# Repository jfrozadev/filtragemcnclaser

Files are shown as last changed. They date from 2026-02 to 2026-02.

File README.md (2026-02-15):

# 📦 CAIXA DE FILTRAGEM 250×250×250mm
## ✅ VERSÃO 13.0 - Cantoneiras M3 + Clips Retenção por Filtro

---

## ⚠️ CORREÇÕES DESTA VERSÃO (CRÍTICAS):

### 🔧 PROBLEMAS ORIGINAIS:
1. Os arquivos originais tinham **dentes e ranhuras nas mesmas posições Y**
2. Os **slots das divisórias** nas laterais foram removidos (trilhos 3D substituem)

### ✅ CORREÇÕES APLICADAS:

**1. Frontal e Traseira - Padrão de dentes INVERTIDO:**
   - Antes: Dentes em Y=25-50, 75-100, 125-150, 175-200, 225-250
   - Agora: Dentes em Y=**0-25**, **50-75**, **100-125**, **150-175**, **200-225**

**2. Sistema de Encaixe Complementar:**
   ```
   LATERAL (ranhuras):    ░░███░░███░░███░░███░░███
   FRONTAL (dentes):      ███░░███░░███░░███░░███░░
   Posição Y:            0  25 50 75 100 ... 225 250
   
   █ = Sólido (25mm)
   ░ = Recuo/Dente (25mm)
   ```

**3. Slots das Divisórias REMOVIDOS:**
   - Divisórias agora deslizam nos trilhos 3D impressos
   - Sem abas nas divisórias, sem slots nas laterais

**4. Lateral Direita ESPELHADA:**
   - Slots espelhados para encaixar corretamente quando montada

**5. Filtro Wega:** 220×160mm (22×16cm) - VERIFICADO ✓

---

## ⚙️ PARÂMETROS DE CORTE

| Parâmetro | Valor |
|---|---|
| **Potência** | S1000 (100%) |
| **Velocidade** | F150 mm/min |
| **Passagens** | 3× |
| **Air Assist** | OBRIGATÓRIO |

---

## 📐 DIMENSÕES DO CUBO 250mm

### Estrutura Principal:
| Peça | Dimensão | Espessura | Qtd |
|---|---|---|-----|
| Laterais (Esq/Dir) | 250×250mm | 3mm | 2 |
| Frontal (entrada) | 244×250mm | 3mm | 1 |
| Traseira (saída) | 244×250mm | 3mm | 1 |
| Tampa | 250×250mm | 3mm | 1 |
| Base | 250×250mm | 3mm | 1 |

### Divisórias (retângulos simples 244×240mm, deslizam nos trilhos):
| Peça | Corpo | Furo do Filtro | Espessura Filtro |
|---|---|---|---|
| Manta G3 | 244×240mm | 200×200mm | **10mm** |
| GM Cabine Bosch | 244×240mm | **212×200mm** (reduzida) | **20mm** |
| Wega Motor | 244×240mm | **223×160mm** | **10mm** |
| **FILTRO HEPA** | 244×240mm | **100×130mm** (reduzida) | borda **2mm** esp. × 5mm larg. |
| Tela Carvão (×2) | 244×240mm | Abertura 200×200mm + 16 furos M3 | — |

### Compartimento de Carvão Ativado:
| Item | Descrição |
|---|---|
| Telas MDF (×2) | 244×240mm com abertura central 200×200mm (11_GAVETA.nc) |
| Caixa MDF (quadro) | 4 bordas ao redor da abertura com encaixe tela (13_CAIXA_CARVAO.nc) |
| Tela alumínio | Mosquiteira fixada com 16 paraf. M3+arruela por tela |
| Posições (slots) | X=190mm (Tela 1) e X=230mm (Tela 2) |
| Espaço interno | 37mm entre telas → ~500g carvão ativado |
| Caixa montada | Quadro 200×200×37mm (4 bordas encaixadas ao redor da abertura) |
| Abas conexão tela | 8 abas (10×3mm) encaixam em 8 slots nas telas, juntando 2 MDF |
| Cantoneiras (3D print) | 16 cantoneiras L-bracket M3 – SNAP_TAMPA.scad |
| Retenção filtro (3D print) | 28 clips paramétricos (8 Manta + 8 GM + 4 Wega + 8 HEPA) – SNAP_TAMPA.scad |

---

## 📁 ARQUIVOS DE CORTE (12 total)

| # | Arquivo | Descrição |
|---|---|---|
| 1 | `01_LATERAL_ESQ.nc` | 250×250mm com ranhuras + furos M3 Ø3.5mm + furos M2 trilhos |
| 2 | `02_LATERAL_DIR.nc` | Idêntica (espelhada) + furos M3 Ø3.5mm + furos M2 trilhos |
| 3 | `03_FRONTAL.nc` | 244×250mm com dentes + furo 70mm + furos M3 Ø3.5mm |
| 4 | `04_TRASEIRA.nc` | 244×250mm com dentes + furo 150mm + furos M3 Ø3.5mm |
| 5 | `05_TAMPA.nc` | 250×250mm + 8 furos M3 Ø3.5mm (cantoneiras) |
| 6 | `06_BASE.nc` | 250×250mm + 8 furos M3 Ø3.5mm + 4 furos pés de borracha |
| 7 | `07_DIVISORIA_MANTA_G3.nc` | 244×240mm + furo 200×200mm + 8 furos M3 Ø3.5mm |
| 8 | `08_DIVISORIA_GM.nc` | 244×240mm + furo **212×200mm** + 8 furos M3 Ø3.5mm |
| 9 | `09_DIVISORIA_WEGA.nc` | 244×240mm + furo **223×160mm** + **4** furos M3 Ø3.5mm |
| 10 | `10_DIVISORIA_HEPA.nc` | 244×240mm + furo **100×130mm** + 8 furos M3 Ø3.5mm |
| 11 | `11_GAVETA.nc` | 2× tela carvão 244×240mm (abertura 200×200, M3 + 8 slots quadro) |
| 12 | `12_FLANGES.nc` | Entrada 70mm + Saída 150mm |
| 13 | `13_CAIXA_CARVAO.nc` | 4× bordas MDF quadro carvão (ao redor abertura, c/ abas tela) |
| 14 | `TRILHO_FILTRO.scad` | Trilhos deslizantes 3D (filtros removíveis, Ender 3) |
| 15 | `TRILHO_PRINT_LAYOUT.scad` | Layout de impressão COMPLETO (10 batches, 200×200mm) |
| 16 | `SNAP_TAMPA.scad` | Cantoneiras M3 + vedação divisória particionada |
| 17 | `FLANGE_150mm.scad` | Flange 150mm (180×180mm base, cabe em 200×200) |
| 18 | `FLANGE_70mm.scad` | Flange 70mm (100×100mm base) |
| 19 | `TRILHO_3D.html` | Visualização 3D interativa dos trilhos |

---

## 🔧 SISTEMA DE ENCAIXE

### Finger Joints (Laterais ↔ Frontal/Traseira):
```
LATERAL (ranhuras):     FRONTAL (dentes):
    ┌───┐                   ├───┤
────┘   └────           ────┤   ├────
 (3mm profundidade)      (3mm salientes)
 
Os DENTES do frontal/traseira entram
nas RANHURAS das laterais!
```

### Divisórias (Deslizam nos Trilhos 3D):
```
LATERAL:               DIVISÓRIA:
   │     │                244×240mm
   │ ███ │ ← trilho 3D    ──────
   │ ││  │                │ MDF │  ← desliza no U
   │ ███ │ ← trilho 3D    ──────
   │     │
   
Trilhos em U fixados com cola CA + Allen M2×5mm
Divisórias deslizam de cima, sem abas/slots
```

### Compartimento Carvão (Quadro ao Redor da Abertura):
```
LATERAL:
   │ ▭ │ X=190mm  (Tela 1)
   │   │  ← quadro carvão (37mm) ao redor da abertura
   │ ▭ │ X=230mm  (Tela 2)
   
VISTA FRONTAL (quadro entre as 2 telas):
   ┌────────────────────────┐
   │  ┌──────────────────┐  │
   │  │  abertura 200×200  │  │ ← borda 22mm da tela
   │  │  (carvão + tela)   │  │
   │  └──────────────────┘  │
   └────────────────────────┘
     ↑ quadro MDF (4 bordas com encaixe tab-slot)

VISTA LATERAL (corte mostrando encaixe):
   Tela2 ═══╤════════╤═══  ← aba atravessa slot
            │ carvão │
            │  37mm  │     ← borda MDF 3mm
            │        │
   Tela1 ═══╧════════╧═══  ← aba atravessa slot

4 bordas MDF formam quadro ao redor da abertura
8 abas (2/borda) atravessam 8 slots nas telas
Encaixes juntam Tela 1 + Quadro + Tela 2
Tela alumínio (mosquiteira) parafusada c/ M3+arruela
16 furos 3.5mm por placa (4 por lado)
Encaixam nos trilhos laterais como as outras divisórias
```

### Trilhos Deslizantes (Filtros Removíveis por Cima):
```
VISTA LATERAL (corte da lateral esquerda):
   TAMPA (remove parafusos M3)
   │                    │
   │  ↑ filtro sobe ↑   │
   │  ┌───────────┐  │
   │╣█╣ divisória  ╣█╣│  ← trilho U impresso 3D
   │╣█╣ MDF 3mm   ╣█╣│    colado na lateral
   │╣█╣           ╣█╣│
   │  └───────────┘  │
   │   └─ trava ─┘   │  ← clipe de retenção (evita cair)
   └──────────────────┘
   BASE

PERFIL DO TRILHO (seção transversal):
   ┌─┐   ┌─┐
   │ │   │ │  ← abas guiam o MDF
   │ ╠═══╣ │  ← canal (esp. filtro + 0.4mm)
   └─┴───┴─┘  ← base (cola no MDF lateral)

2 METADES com junta reta (122mm + 122mm = 244mm):
   Cabe na Ender 3 (200×200mm)
   Fixadas com cola CA + parafuso M2 (sem dovetail)
```

| Filtro | Pos X | Canal | Peças (2×metade A + 2×metade B) |
|---|---|---|---|
| Manta G3 | 50mm | 17mm | 4 |
| GM Cabine | 75mm | 21mm | 4 |
| Wega Motor | 125mm | 46mm | 4 |
| HEPA | 155mm | 26mm | 4 |
| Tela Carvão 1 | 190mm | 3.4mm | 4 |
| Tela Carvão 2 | 230mm | 3.4mm | 4 |
| **TOTAL** | | | **24 + 6 puxadores + 6 travas = 36** |

### 🖨️ LAYOUT IMPRESSÃO 3D (Ender 3 - 200×200mm)

**Todas as peças cabem na mesa de 200×200mm!**

| Batch | Peças | Qtd | Tempo | Tamanho |
|---|---|-----|---|---|
| 1 | Trilhos Tela Carvão (3.4mm) | 8 | ~50min | 80×122mm ✓ |
| 2 | Trilhos Manta G3 (17mm) | 4 | ~1h | 88×122mm ✓ |
| 3 | Trilhos GM Cabine (21mm) | 4 | ~1h20 | 109×122mm ✓ |
| 4 | Trilhos HEPA (26mm) | 4 | ~1h30 | 129×122mm ✓ |
| 5A | Trilhos Wega A (46mm) | 2 | ~1h | 103×122mm ✓ |
| 5B | Trilhos Wega B (46mm) | 2 | ~1h | 103×122mm ✓ |
| 6 | Puxadores + Travas | 12 | ~45min | 200×33mm ✓ |
| 7 | Cantoneiras + Retenção | 44 | ~5h30 | 184×135mm ✓ |
| 8 | Vedação Divisória (8 seg) | 8 | ~1h30 | 130×65mm ✓ |
| 9 | Flange 150mm | 1 | ~3h | 180×180mm ✓ |
| 10 | Flange 70mm | 1 | ~1h30 | 100×100mm ✓ |
| **TOTAL** | | **62** | **~15h30** | |

**Arquivo:** `TRILHO_PRINT_LAYOUT.scad` — abrir no OpenSCAD, descomentar batch desejado, F6+F7 para exportar STL.

### Sistema de Fixação:
```
CANTONEIRAS M3 (fechar caixa - tampa + base):
  16 cantoneiras L-bracket impressas em PLA/PETG
  Flange horiz: 20×15×3mm | Flange vert: 20×18×3mm
  Furos M3 Ø3.5mm nos 6 painéis (tampa, base, 4 paredes)
  Fixação: 32× M3×8mm + 32× porca M3 (2 por cantoneira)
  Posições laterais: X=100mm X=173mm, a Y=10mm (base) e Y=240mm (topo)
  Posições frontal/traseira: X=82mm X=162mm, a Y=10mm e Y=240mm
  Abertura fácil: desapertar 16 parafusos pela tampa → tampa sai
  Vedação: compressão MDF-cantoneira + fita vedação opcional

RETENÇÃO FILTRO (fixar filtro na divisória - parafuso M3):
  28 clips retenção impressos em PLA/PETG
  8 Manta G3 + 8 GM Cabine + 4 Wega + 8 HEPA
  Base: 20×15×3mm | Braço: 20×2×12mm | Aba: 20×10×2mm
  8 furos M3 Ø3.5mm por divisória ao redor da abertura do filtro:
    Manta G3: (12,80)(12,160)(232,80)(232,160)(88,10)(156,10)(88,230)(156,230)
    GM Cabine: (5,80)(5,160)(239,80)(239,160)(82,7)(162,7)(82,232)(162,232)
    Wega: (6,80)(6,160)(238,80)(238,160)(82,19)(162,19)(82,221)(162,221)
    HEPA: (57,90)(57,150)(187,90)(187,150)(102,40)(142,40)(102,200)(142,200)
  Fixação: parafuso M3×10mm + porca M3

TOTAL: 44 peças (16 cantoneiras + 28 clips retenção filtro)

Vedação divisória (opcional):
  8 segmentos com encaixes dovetail (~122mm cada)
  Particionada para caber na mesa 200×200mm
```

---

## 🛠️ ORDEM DE MONTAGEM

1. **Base** → Colocar na mesa
2. **Lateral Esquerda** → Cole sobre a borda da base
3. **Lateral Direita** → Paralela, a 244mm de distância
4. **Frontal** → Dentes nos slots das laterais
5. **Traseira** → Igual ao frontal
6. **Trilhos 3D** → Fixar nas laterais com cola CA + parafuso Allen M2×5mm (furos Ø2.5mm pré-cortados, 12/lateral)
7. **Divisórias filtro** → Deslizar de cima pelos trilhos + fixar cada filtro com 8 clips retenção (M3×10mm) ao redor da abertura
8. **Telas carvão (×2)** → Deslizar nos trilhos X=190 e X=230
9. **Caixa carvão** → Encaixar 4 tiras + preencher com carvão
10. **Tampa** → Posicionar no topo, fixar com 16 cantoneiras + 32 parafusos M3×8mm

---

## 🎯 VERIFICAÇÃO 3D

Abra `MONTAGEM_3D.html` no navegador para:
- Ver a montagem passo a passo (12 passos)
- Verificar encaixes visuais, incluindo trilhos
- Rotacionar e dar zoom no modelo

Abra `TRILHO_3D.html` para:
- Ver trilhos deslizantes em detalhe
- Animar deslizamento dos filtros
- Ver encaixe dovetail das 2 metades

| Divisória | Posição X | Espessura | Espaço até próximo | Função |
|---|---|---|---|---|
| *(plenum entrada)* | *3mm* | — | *47mm→G3* | *Expansão do ar (47mm)* |
| Manta G3 | **50mm** | 10mm | 22mm→GM | Pré-filtro (partículas grandes) |
| GM Cabine Bosch | **75mm** | 20mm | 47mm→Wega | Filtro cabine (partículas médias) |
| Wega Motor | **125mm** | 45mm | 27mm→HEPA | Filtro motor (partículas finas) |
| **FILTRO HEPA** | **155mm** | 25mm | 32mm→Tela 1 | **Filtro HEPA** |
| Tela Carvão 1 | **190mm** | 3mm (MDF) | 37mm→Tela 2 | Retém carvão (lado interno) |
| Tela Carvão 2 | **230mm** | 3mm (MDF) | 17mm→Traseira | Retém carvão (lado traseira) |

---

## 📋 MATERIAIS

- MDF 3mm: ~15 chapas 300×300mm
- Manta G3 (pré-filtro) 10mm - fixada com 8 clips 3D (CLIP_MANTA_G3.scad)
- Filtro GM Cabine Bosch 20mm
- Filtro Wega Motor 45mm
- **Filtro HEPA** (110×140×25mm)
- Carvão ativado ~500g (granulado)
- Tela alumínio mosquiteira (2× para telas carvão)
- 32× Parafuso M3 + arruela (16 por tela)
- Cola PVA + Silicone
- 16× Cantoneiras L-bracket impressas em PLA/PETG (SNAP_TAMPA.scad)
- 32× Parafuso M3×8mm + 32× porca M3 (fixação cantoneiras tampa/base)
- 28× Clips retenção filtro impressos em PLA/PETG (SNAP_TAMPA.scad)
- 28× Parafuso M3×10mm + 28× porca M3 (fixação clips retenção nas divisórias)
- 24× Trilhos deslizantes impressos em PLA/PETG (TRILHO_FILTRO.scad)
- 6× Puxadores + 6× Travas impressos (TRILHO_FILTRO.scad)
- 8× Vedação divisória (opcional) impressos (SNAP_TAMPA.scad)
- 2× Flanges impressos (FLANGE_150mm.scad + FLANGE_70mm.scad)
- 24× Parafuso Allen M2×5mm (fixação trilhos, 12 por lateral — rosca no PLA, sem porca)
- Filamento PLA/PETG ~150g

---

**Versão:** 13.0 — Cantoneiras M3 (tampa/base) + clips retenção filtro (divisórias)  
**Data:** Fevereiro 2026

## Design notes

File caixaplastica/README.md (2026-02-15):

# 📦 CAIXA PLÁSTICA FILTRAGEM
## Caixa Organizadora Ordene 30L (307×425×305mm)
### MDF 300×300×3mm INTEIRO — só corte da abertura + furos M3

---

## 💡 CONCEITO

Caixa plástica comercial como estrutura. **MDF 300×300mm usado inteiro** (sem cortar o contorno externo).
O MDF encaixa justo na largura interna da caixa (~301mm). Guias 3D no fundo (50mm de altura) + **barras anti-tombo** no aro superior mantêm cada divisória firme.

```
┌─────────── CAIXA PLÁSTICA ───────────┐
│  ══ BARRA ANTI-TOMBO (aro) ══════    │ ← segura topo do MDF
│  MDF 300mm ← encaixa justo (301mm) → │
│  ┌───────────────────────────────┐    │
│  │        ┌──────────┐          │    │
│  │        │ ABERTURA │  ← laser │    │
│  │        │ FILTRO   │          │    │
│  │        └──────────┘          │    │
│  │     (furos M3 ao redor)      │    │
│  └───────────────────────────────┘    │
│  ──█──────────────────────────█──    │ ← guias piso 50mm
└───────────────────────────────────────┘
```

### Sustentação do MDF:
- ✅ **Embaixo**: Guias piso U (50mm alt.) — coladas no fundo
- ✅ **Em cima**: Barras anti-tombo — apoiam no aro da caixa
- ✅ **Laterais**: Paredes da caixa (301mm vs 300mm MDF)
- ✅ **3 eixos de contenção** → MDF não tomba!

### Vantagens:
- ✅ **Zero corte externo** — só abertura + furos
- ✅ Caixa pronta, vedada, com tampa
- ✅ MDF 300×300 direto da loja (sem desperdiço)
- ✅ Guias piso coladas + barras topo — **MDF não tomba!**
- ✅ Divisórias removíveis (levanta e sai)
- ✅ Menos tempo de laser (só aberturas)

---

## 📐 DIMENSÕES

### Caixa Plástica (Ordene Radical Color 30L):
| Parâmetro | Valor |
|---|---|
| **Modelo** | Caixa Organizadora Plástico Transparente 30L |
| **Código** | 87164742 (Leroy Merlin) |
| **EAN** | 7898335072150 |
| **Externo** | 307 × 425 × 305 mm (L × P × A) |
| **Interno (est.)** | ~301 × 419 × 297 mm |
| **Parede** | ~3mm PP |

> ⚠️ **MEÇA SUA CAIXA!** Ajuste os parâmetros no OpenSCAD se necessário.

### MDF:
| Parâmetro | Valor |
|---|---|
| **Chapa** | 300 × 300 × 3 mm (padrão, sem cortar) |
| **Encaixe** | 300mm no vão de 301mm (0.5mm folga/lado) |
| **Altura** | 300mm (sobra ~3mm acima do interno — ok com tampa) |

### Guia de Posição PISO (3D print):
| Parâmetro | Valor |
|---|---|
| **Tipo** | Canal U colado no fundo |
| **Canal** | 3.4mm (MDF 3 + folga 0.4) |
| **Paredes** | 1.5mm cada |
| **Base** | 6.4mm × 2mm |
| **Altura guia** | **50mm** (anti-tombo) |
| **Comprimento** | 80mm |
| **Fixação** | Super Bonder gel |
| **Qtd** | 12 (6 posições × 2 lados) |

### Barra Anti-Tombo (3D print):
| Parâmetro | Valor |
|---|---|
| **Tipo** | Barra com rasgos — apoiada no aro da caixa |
| **Largura** | 15mm (assenta no aro) |
| **Altura** | 20mm |
| **Rasgo** | 3.4mm × 14mm prof. (MDF entra por baixo) |
| **Seção 1** | 135mm — G3 + GM + Wega (3 rasgos) |
| **Seção 2** | 125mm — HEPA + C1 + C2 (3 rasgos) |
| **Fixação** | Apoio por gravidade (não precisa cola) |
| **Qtd** | 4 (2 seções × 2 lados) |

---

## 🎯 LAYOUT DOS FILTROS

```
ENTRADA Ø70mm                                    SAÍDA Ø150mm
    │                                                 │
    ▼                                                 ▼
┌───┬───┬────┬─────┬──────┬────┬───┬───┬───┬────┬────┐
│   │G3 │    │ GM  │      │WEGA│   │HPA│   │ C1 │ C2 │
│50 │   │ 95 │     │ 165  │    │245│   │310│    │350 │
└───┴───┴────┴─────┴──────┴────┴───┴───┴───┴────┴────┘
0mm              profundidade (425mm ext)            419mm
```

| # | Divisória | Pos Y | Abertura | Esp. Filtro | Furos M3 |
|---|---|---|---|---|---|
| 1 | Manta G3 | 50mm | 200×200mm | 10mm | 8 |
| 2 | GM Cabine | 95mm | 212×200mm | 20mm | 8 |
| 3 | Wega Motor | 165mm | 223×160mm | 45mm | 4 |
| 4 | HEPA | 245mm | 100×130mm | 25mm | 8 |
| 5 | Tela Carvão 1 | 310mm | 200×200mm | 3mm (MDF) | 16 |
| 6 | Tela Carvão 2 | 350mm | 200×200mm | 3mm (MDF) | 16 |

### Espaçamentos:
| Trecho | mm | Função |
|---|----|---|
| Parede → G3 | 50 | Plenum entrada |
| G3 → GM | 35 | Expansão |
| GM → Wega | 50 | Expansão |
| Wega → HEPA | 35 | Expansão |
| HEPA → Tela 1 | 40 | Expansão |
| Tela 1 → Tela 2 | 37 | Carvão ativado (~700g) |
| Tela 2 → Parede | 66 | Plenum saída |

---

## ⚙️ CORTE CNC LASER

| Parâmetro | Valor |
|---|---|
| **CNC** | Two Trees TTS-10 |
| **Material** | MDF 3mm |
| **Potência** | S900 |
| **Velocidade** | F200 mm/min |
| **Passagens** | 4× |
| **Air Assist** | OBRIGATÓRIO |

**Importante:** Os NC files cortam APENAS a abertura e os furos M3. O contorno externo 300×300mm **NÃO é cortado**.

---

## 📁 ARQUIVOS

### Corte CNC (5 divisórias):
| # | Arquivo | Abertura | Furos M3 |
|---|---|---|---|
| 1 | `01_DIVISORIA_MANTA_G3.nc` | 200×200mm em (50,50) | 8 |
| 2 | `02_DIVISORIA_GM.nc` | 212×200mm em (44,50) | 8 |
| 3 | `03_DIVISORIA_WEGA.nc` | 223×160mm em (38.5,70) | 4 |
| 4 | `04_DIVISORIA_HEPA.nc` | 100×130mm em (100,85) | 8 |
| 5 | `05_TELA_CARVAO.nc` | 200×200mm em (50,50) | 16 (×2 chapas) |

### Impressão 3D:
| # | Arquivo | Descrição |
|---|---|---|
| 6 | `GUIA_POSICAO.scad` | Guia U parametrizável (OpenSCAD) |

### Visualização:
| # | Arquivo | Descrição |
|---|---|---|
| 7 | `MONTAGEM_3D.html` | Montagem 3D interativa (12 passos) |

### Reutilizados (pasta pai):
| Arquivo | Descrição |
|---|---|
| `../FLANGE_70mm.scad` | Flange entrada Ø70mm |
| `../FLANGE_150mm.scad` | Flange saída Ø150mm |
| `../SNAP_TAMPA.scad` | Clips retenção filtro (M3) |

---

## 🔧 FUROS NA CAIXA (Furadeira)

### Apenas flanges! (serra-copo)
```
FRONTAL:                      TRASEIRA:
┌──────────────────┐          ┌──────────────────┐
│    ┌────────┐    │          │  ┌────────────┐  │
│    │ Ø70mm  │    │          │  │  Ø150mm    │  │
│    │ENTRADA │    │          │  │  SAÍDA     │  │
│    └────────┘    │          │  └────────────┘  │
│ centro: ~153×152 │          │ centro: ~153×152 │
└──────────────────┘          └──────────────────┘
```

**Laterais: SEM FUROS** — guias são coladas com Super Bonder gel.

---

## 🛠️ ORDEM DE MONTAGEM

1. **Caixa plástica** → Limpar e marcar posições internas
2. **Furar flanges** → Serra-copo Ø70mm (frente) e Ø150mm (atrás)
3. **Instalar flanges 3D** → Parafusar nas faces da caixa
4. **Marcar posições no fundo** → Régua: Y=50, 95, 165, 245, 310, 350mm
5. **Colar guias piso** → Super Bonder gel, 12 guias (50mm alt.) — 2 por posição
6. **Encaixar barras anti-tombo** → 4 barras no aro da caixa (2 seções × 2 lados)
7. **Cortar divisórias** → CNC laser: 7 chapas MDF 300×300mm (só abertura + furos)
8. **Manta G3** → Encaixar MDF na guia Y=50, fixar filtro com 8 clips M3
9. **GM Cabine** → Guia Y=95, filtro 20mm + 8 clips
10. **Wega Motor** → Guia Y=165, filtro 45mm + 4 clips
11. **HEPA** → Guia Y=245, filtro HEPA 25mm + 8 clips
12. **Tela Carvão 1** → Guia Y=310, tela alumínio (16 M3+arruela)
13. **Carvão** → ~700g carvão ativado granulado
14. **Tela Carvão 2** → Guia Y=350, tela alumínio
15. **Tampa** → Fechar com trava original da caixa

---

## 🖨️ IMPRESSÃO 3D

### Guias piso (1 batch):
| Peças | Tamanho cada | Tempo | Filamento |
|---|---|---|---|
| 12 guias (6 pos × 2) | 6.4×80×52mm | ~1h | ~25g |

### Barras anti-tombo (1 batch):
| Peças | Tamanho | Tempo | Filamento |
|---|---|---|---|
| 2× Seção 1 | 135×15×20mm | ~30min | ~8g |
| 2× Seção 2 | 125×15×20mm | ~25min | ~7g |

### Acessórios (pasta pai):
| Item | Qtd | Tempo |
|---|-----|---|
| Flange 70mm | 1 | ~1h30 |
| Flange 150mm | 1 | ~3h |
| Clips retenção | 28 | ~4h |

**Total: ~10h de impressão | ~140g PLA/PETG**

---

## 📋 LISTA DE MATERIAIS

| Item | Qtd | Observação |
|---|-----|---|
| Caixa Ordene 30L | 1 | 307×425×305mm (Leroy Merlin) |
| **MDF 300×300×3mm** | **7** | **Usadas inteiras — sem corte externo** |
| Manta G3 (pré-filtro) | 1 | 200×200×10mm |
| Filtro GM Cabine Bosch | 1 | 212×200×20mm |
| Filtro Wega Motor | 1 | 223×160×45mm |
| Filtro HEPA | 1 | 110×140×25mm |
| Carvão ativado | ~700g | Granulado |
| Tela alumínio mosquiteira | 2× | 250×250mm recortada |
| Parafuso M3×10mm + porca | ~80× | Clips + tela alumínio |
| Arruela M3 | 64× | 32 por tela carvão |
| Super Bonder gel | 1 | Fixar guias no fundo |
| Filamento PLA/PETG | ~100g | Guias + flanges + clips |
| Serra-copo Ø70 + Ø150mm | 1+1 | Para furar flanges |

---

## 🎯 VERIFICAÇÃO 3D

Abra `MONTAGEM_3D.html` no navegador:
- **12 passos interativos** (incluindo barras anti-tombo no passo 6)
- Setas ←→, barra de espaço, Home/End para navegar
- Botão "Mostrar Tudo" para ver montagem completa
- Rotacionar e zoom com mouse

---

**Versão:** 3.0 — Guias 50mm + Barras anti-tombo  
**Data:** Fevereiro 2026

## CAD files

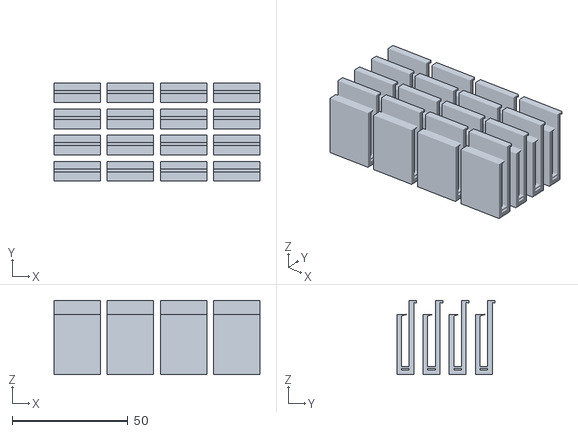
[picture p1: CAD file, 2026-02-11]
PRINT_SNAP_CLIPS.stl
89.0 x 42.4 x 32.0

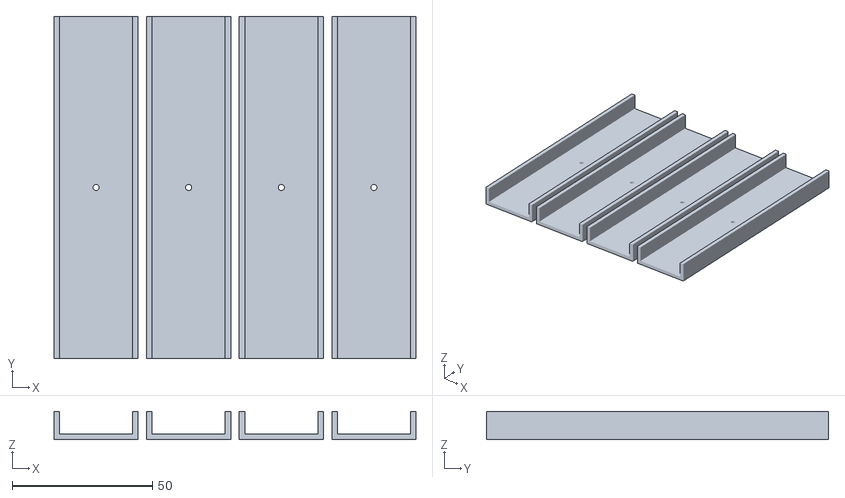
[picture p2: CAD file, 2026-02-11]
PRINT_HEPA.stl
129.0 x 122.0 x 10.0

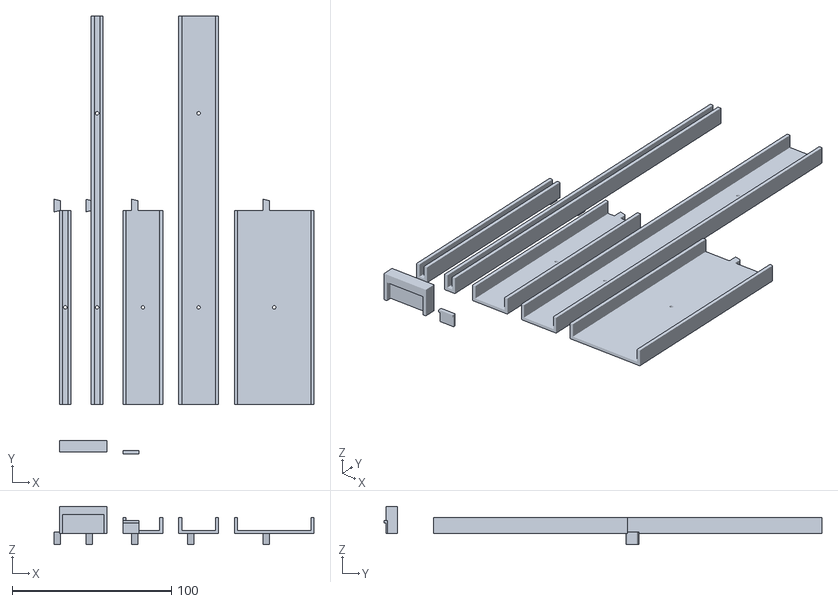
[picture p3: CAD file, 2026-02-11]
TRILHO_FILTRO.stl
163.4 x 275.0 x 24.0

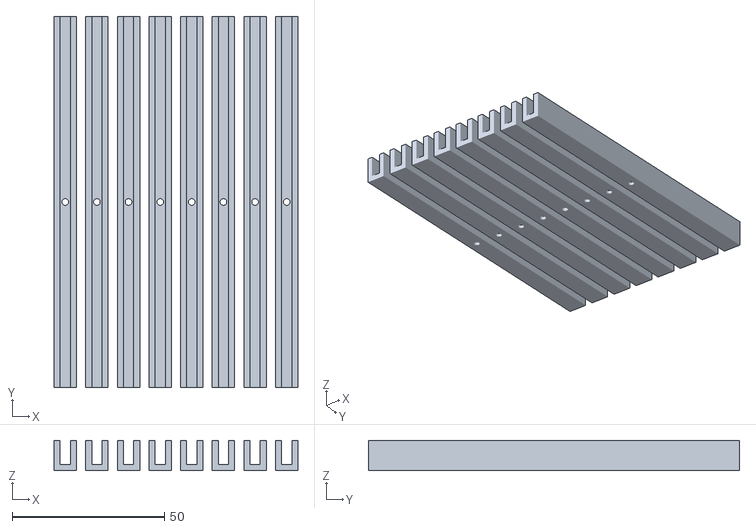
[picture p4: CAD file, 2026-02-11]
TRILHO_PRINT_LAYOUT.stl
80.2 x 122.0 x 10.0

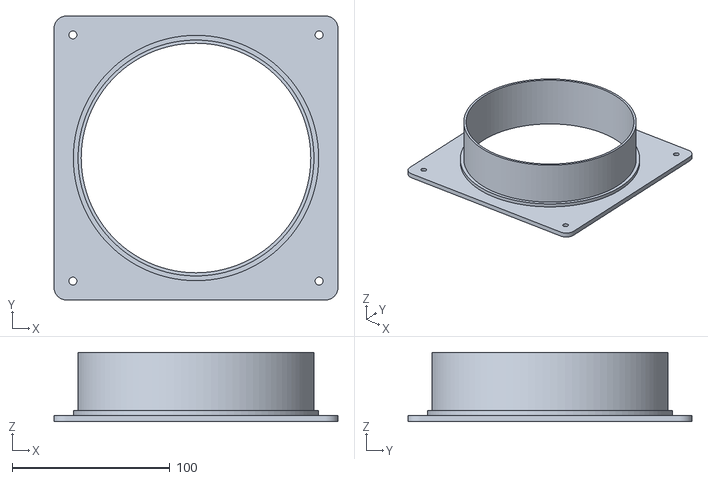
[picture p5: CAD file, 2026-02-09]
FLANGE_150mm.stl
180.0 x 180.0 x 44.0

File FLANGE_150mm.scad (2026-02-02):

// =====================================================
// FLANGE CONECTOR PARA TUBO DE 150mm
// Caixa de Filtragem - Exaustão
// =====================================================
// Para imprimir: Exportar como STL (F6 depois F7)
// Material sugerido: PETG ou ABS
// Preenchimento: 20-30%
// Paredes: 3-4 perímetros
// =====================================================

// PARÂMETROS AJUSTÁVEIS
tubo_diametro = 150;        // Diâmetro interno do tubo (mm)
tubo_espessura = 2;         // Espessura da parede do conector (mm)
tubo_altura = 40;           // Altura do tubo/bocal (mm)
tubo_folga = 0.5;           // Folga para encaixe (mm)

flange_tamanho = 180;       // Tamanho da base quadrada (mm)
flange_espessura = 4;       // Espessura da base (mm)
flange_raio_canto = 8;      // Raio dos cantos arredondados (mm)

furo_diametro = 5;          // Diâmetro dos furos de fixação (mm)
furo_margem = 12;           // Distância do furo até a borda (mm)

// Opção: tubo interno ou externo
// true = tubo encaixa POR DENTRO do duto (mais comum)
// false = tubo encaixa POR FORA do duto
encaixe_interno = true;

// =====================================================
// CÓDIGO - NÃO MODIFICAR ABAIXO
// =====================================================

$fn = 100; // Resolução dos círculos

// Cálculo do diâmetro do bocal
diametro_bocal = encaixe_interno ? 
    tubo_diametro - tubo_folga : 
    tubo_diametro + tubo_espessura*2 + tubo_folga;

module flange_base() {
    // Base quadrada com cantos arredondados
    difference() {
        // Placa base
        hull() {
            for (x = [flange_raio_canto, flange_tamanho - flange_raio_canto])
                for (y = [flange_raio_canto, flange_tamanho - flange_raio_canto])
                    translate([x, y, 0])
                        cylinder(h = flange_espessura, r = flange_raio_canto);
        }
        
        // Furo central para passagem de ar
        translate([flange_tamanho/2, flange_tamanho/2, -1])
            cylinder(h = flange_espessura + 2, d = tubo_diametro - tubo_espessura*2);
        
        // Furos de fixação nos 4 cantos
        for (x = [furo_margem, flange_tamanho - furo_margem])
            for (y = [furo_margem, flange_tamanho - furo_margem])
                translate([x, y, -1])
                    cylinder(h = flange_espessura + 2, d = furo_diametro);
    }
}

module tubo_bocal() {
    translate([flange_tamanho/2, flange_tamanho/2, flange_espessura]) {
        difference() {
            // Tubo externo
            cylinder(h = tubo_altura, d = diametro_bocal);
            
            // Furo interno
            translate([0, 0, -1])
                cylinder(h = tubo_altura + 2, d = diametro_bocal - tubo_espessura*2);
        }
        
        // Anel de reforço na base
        difference() {
            cylinder(h = 3, d = diametro_bocal + 6);
            translate([0, 0, -1])
                cylinder(h = 5, d = diametro_bocal - tubo_espessura*2);
        }
    }
}

module flange_completa() {
    color("white") {
        flange_base();
        tubo_bocal();
    }
}

// Renderizar
flange_completa();

// Info
echo("=== FLANGE 150mm ===");
echo("Diâmetro do tubo:", tubo_diametro, "mm");
echo("Diâmetro do bocal:", diametro_bocal, "mm");
echo("Base:", flange_tamanho, "x", flange_tamanho, "mm");
echo("Altura total:", flange_espessura + tubo_altura, "mm");

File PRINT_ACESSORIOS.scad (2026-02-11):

// ============================================================
// PRINT: ACESSÓRIOS — Puxadores + Travas
// 6× puxadores (30×7.4×17mm) + 6× travas (10×2.2×8mm)
// Mesa: ~200mm × 33mm — cabe na Ender 3 (200×200mm) ✓
// Tempo estimado: ~45min
// ============================================================

use <TRILHO_FILTRO.scad>

gap = 3;

// 6 puxadores em 2 fileiras de 3
for (i = [0:2]) {
    translate([i * 35, 0, 0])
        puxador();
}
for (i = [0:2]) {
    translate([i * 35, 25, 0])
        puxador();
}

// 6 travas ao lado dos puxadores
for (i = [0:5]) {
    translate([110 + i * 15, 0, 0])
        trava();
}

// Guia visual da mesa (não imprime)
%translate([0, 0, -0.5])
    cube([200, 200, 0.1]);

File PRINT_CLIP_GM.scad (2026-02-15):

// ============================================================
// PRINT: CLIPS RETENÇÃO — GM CABINE
// 8 unidades — braço 23mm (espessura filtro 20mm + MDF 3mm)
// Mesa: ~89mm × 56mm — cabe na Ender 3 (200×200mm) ✓
// Divisória: 08_DIVISORIA_GM — Abertura 212×200mm
// ============================================================
// Design estilo clip HVAC (perfil Z com aba sobre o filtro)
// Orientação: base na mesa (Z=0), braço+aba para cima
// Infill recomendado: 80-100%
// Material: PETG (melhor) ou PLA
// Parafusos: 8× M3×16mm + 8× porca M3
// ============================================================
// Posições M3 na divisória (coordenadas NC):
//   (8,80)(8,160)(236,80)(236,160)
//   (82,10)(162,10)(82,230)(162,230)
// ============================================================

use <SNAP_TAMPA.scad>

gap = 3;
ret_w = 20;
aba_y = 8;            // offset Y para aba que estende em -Y
row_h = 15 + aba_y;   // altura total Y por clip = base + aba

// 4 colunas × 2 fileiras = 8 clips GM Cabine (braço 23mm)
for (row = [0:1]) {
    for (col = [0:3]) {
        translate([col * (ret_w + gap), row * (row_h + gap) + aba_y, 0])
            clip_gm();
    }
}

// Guia visual da mesa (não imprime)
%translate([0, 0, -0.5])
    cube([200, 200, 0.1]);

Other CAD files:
FLANGE_70mm.3mf
FLANGE_70mm.scad
FLANGE_70mm.stl
PRINT_CLIP_HEPA.scad
PRINT_CLIP_MANTA.scad
PRINT_CLIP_WEGA.scad
PRINT_GM_CABINE.scad
PRINT_HEPA.scad
PRINT_MANTA_G3.scad
PRINT_SNAP_CLIPS.scad
PRINT_TELA_CARVAO.scad
PRINT_VEDACAO.scad
PRINT_WEGA.scad
SNAP_TAMPA.scad
TRILHO_FILTRO.scad
TRILHO_PRINT_LAYOUT.scad
caixaplastica/GUIA_POSICAO.scad

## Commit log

2026-02-02 Commit inicial - Projeto de Exaustao para CNC Router
    [FLANGE_150mm.scad, FLANGE_70mm.scad]
2026-02-02 Atualizar espessuras corretas dos filtros e etapas individuais na animacao 3D - Wega 50mm, GM Bosch 20mm, HEPA 45mm - Gravacao FILTRO HEPA no arquivo NC
2026-02-02 Redistribuir posicoes dos filtros para espacamento uniforme de 15mm
2026-02-02 Corrigir arquivos de corte das laterais - 4 slots nas novas posicoes (15, 45, 80, 145mm)
2026-02-09 feat: update filter dimensions and simplify G3 divider
    - HEPA filter: 130x250x45mm -> 110x140x25mm (hole 110x140mm centered)
    - Wega filter: 220x160x50mm -> 220x160x45mm (hole 220x160mm corrected)
    - GM cabin filter: 205x220x20mm -> 223x210x20mm (hole 223x210mm centered)
    - Manta G3: simplified from 2-plate sandwich to single plate with glued mesh + clamps (10mm thickness)
    - Updated all NC files with recalculated coordinates (3 passes each)
    - Updated MONTAGEM_3D.html and MODELO_3D.html with correct 3D geometry
    - Updated README.md with new dimensions, spacings and materials
    [FLANGE_150mm.stl, FLANGE_70mm.3mf, FLANGE_70mm.stl]
2026-02-09 feat: compartimento carvao vertical c/ telas MDF + mosquiteira M3
    - 11_GAVETA.nc: 2x placa 244x244mm abertura 200x200mm + 16 furos 3.5mm M3+arruela
    - 01/02 LATERAL: +2 slots carvao (X=180, X=215) espelhados
    - MONTAGEM_3D: createCarbonCompartment() c/ telas verticais, parafusos, mosquiteira
    - SNAP_TAMPA.scad: clips snap-fit tampa + vedacao divisorias (OpenSCAD)
    - README: atualizado materiais, montagem, compartimento carvao
    - Tampa: snap-fit sem parafusos (descricao atualizada)
    [SNAP_TAMPA.scad]
2026-02-09 feat(carvao): redesenhar quadro carvao com bordas ao redor da abertura e encaixes tela
    - Reescrever 13_CAIXA_CARVAO.nc: quadro 200x200x42mm ao redor da abertura
    - 4 bordas MDF com juntas tab-slot nos cantos (8 encaixes)
    - 16 abas (10x3mm) que atravessam slots nas telas, juntando 2 MDF
    - Adicionar 8 slots retangulares (10x3mm) em 11_GAVETA.nc
    - 2 por borda (esq/dir/inf/sup) na borda da abertura 200x200
    - 3 passagens de corte para cada slot
    - Atualizar MONTAGEM_3D.html: posicoes divisorias corrigidas,
    snap-fit clips substituem parafusos, caixa carvao 3D
    - Atualizar SNAP_TAMPA.scad: 16 clips (8+8), pernas 30/24mm,
    slots 22x2mm, instrucoes impressao
    - Adicionar SNAP_FIT_3D.html: visu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
    [SNAP_TAMPA.scad]
2026-02-09 feat(trilhos): adicionar trilhos deslizantes 3D para filtros removiveis
    - TRILHO_FILTRO.scad: design parametrico OpenSCAD
    - perfil U com canal ajustavel por filtro
    - 2 metades com dovetail (122mm+122mm) cabe na Ender 3
    - 6 pares de trilhos (Manta G3, GM, Wega, HEPA, 2x Tela)
    - puxador e trava de retencao inclusos
    - total: 24 trilhos + 6 puxadores + 6 travas = 36 pecas
    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
    [TRILHO_FILTRO.scad]
2026-02-09 feat(trilhos): criar arquivos completos trilhos e atualizar modelos 3D
    Novos arquivos:
    - TRILHO_3D.html: visualizacao 3D interativa dos trilhos
    - animacao deslizar filtros, encaixe dovetail, explodir
    - toggle individual por filtro (G3/GM/Wega/HEPA/Telas)
    - tabela dimensoes e legenda completa
    - TRILHO_PRINT_LAYOUT.scad: layout impressao Ender 3
    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
    [TRILHO_PRINT_LAYOUT.scad]
2026-02-09 fix: corrigir posicoes filtros 3D e layout impressao
    MODELO_3D.html:
    - Corrigir posicoes divisorias (mantag3=0.15, gm=0.40, wega=0.90)
    - Adicionar HEPA (x=1.20), Tela1 (x=1.65), Tela2 (x=2.10)
    - Filtros posicionados upstream (entre divisoria anterior e atual)
    - Adicionar filtro HEPA na visualizacao
    - Corrigir posicao carvao ativado (entre telas, x=1.875)
    - Corrigir animacoes para 6 divisorias
    - Corrigir funcao explodir para todas divisorias
    MONTAGEM_3D.html:
    - Filtros posicionados upstream (posX - fDepth/2)
    - Resolve sobreposicao Wega/HEPA
    TRILHO_3D.html:
    - Filtros posicionados upstream (f.x - espScale/2)
    - homeX em userData para reset correto
    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
    [TRILHO_PRINT_LAYOUT.scad]
2026-02-09 fix: caixa carvao 3D fiel ao NC (200x200x42mm)
    MONTAGEM_3D.html createCarbonCompartment():
    - stripDepth corrigido: carbonDepth-T = 0.42 (42mm corpo quadro)
    - Tiras verticais: 200mm altura (era 244mm)
    - Tiras horizontais: 194mm largura (era 238mm)
    - Posicoes: ao redor da abertura 200x200mm das telas
    (antes estava contra as paredes laterais da caixa)
    - carbonEdges wireframe: 200x200x42mm (era 244x244x45mm)
    - Carvao volume proporcional ao quadro interno
    - Comentarios corrigidos (frameSize=200mm, stripDepth=42mm)
2026-02-09 refactor: reposicionar filtros - 35mm plenum entrada, corpo carvao 37mm
    Problema: filtro Manta G3 a apenas 2mm da face interna frontal.
    Jato do exaustor (70mm) atingia diretamente o centro do filtro
    sem expansao, causando filtragem desigual e entupimento precoce.
    Novas posicoes (centro do slot, mm desde frontal):
    Manta G3: 15 -> 50 (47mm plenum para expansao do ar)
    GM Cabine: 40 -> 75 (22mm gap apos G3)
    Wega: 90 -> 125 (47mm gap apos GM)
    HEPA: 120 -> 155 (27mm gap apos Wega)
    Tela 1: 165 -> 190 (32mm gap apos HEPA)
    Tela 2: 210 -> 230 (37mm corpo carvao)
    Snap-fit reposicionados: X=105/145 -> X=100/173
    Caixa carvao: corpo 42->37mm, tira 48->43mm
    Arquivos alt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
    [TRILHO_FILTRO.scad]
2026-02-09 fix: snap-fit clips 3D geometry (U-bracket conforme SNAP_TAMPA.scad)
    Tampa: clip antigo era L simples (1 perna + gancho).
    Agora mostra bracket em U correto: ponte + perna externa
    30mm + perna interna 24mm + 2 ganchos (conforme SCAD).
    Base: antes mostrava slots escuros dentro do MDF.
    Agora mostra 8 clips invertidos (pernas para cima)
    identicos aos da tampa, espelhados verticalmente.
2026-02-09 simplify: remover furos parafuso da tampa e base (snap-fit nao precisa)
    Tampa: era 287 linhas com 10 furos de parafuso (3 passes cada).
    Agora 112 linhas: so perimetro 250x250mm + gravacao TAMPA.
    Fixacao 100% por clips snap-fit U-bracket.
    Base: removidos 10 furos de parafuso. Mantidos 4 furos
    para pes de borracha (10mm). 339 -> 174 linhas.
    README atualizado com novas descricoes.
2026-02-09 feat: furos M2 fixação trilhos nas laterais + 3D atualizado
    - 01_LATERAL_ESQ.nc: +36 furos Ø2.5mm (M2) para fixação dos trilhos (3 passes)
    - 02_LATERAL_DIR.nc: +36 furos espelhados Ø2.5mm (M2) (3 passes)
    - TRILHO_FILTRO.scad: corrigido array canais (posições atualizadas) + comentário fixação
    - MONTAGEM_3D.html: furos M2 visíveis nas laterais + texto passo 6 atualizado
    - README.md: passo 6, descrição laterais, materiais (72x M2), versão 9.0
    Posições Y dos furos (por trilho): 33.5, 64.0, 94.5, 155.5, 186.0, 216.5mm
    Derivadas de: trilho_comp(122mm) × i/(n_furos+1), i=1..3, para cada metade
    [TRILHO_FILTRO.scad]
2026-02-09 Reduz furos M2 trilhos: 36→12 por lateral (1/metade centro)
    - Cola CA fixação primária, parafusos M2 apenas reforço
    - Y=64mm (centro metade A) + Y=186mm (centro metade B)
    - 6 trilhos × 2 furos = 12/lateral, 24 total (era 72)
    - TRILHO_FILTRO.scad: n_furos 3→1
    - MONTAGEM_3D.html: furoYpositions [6]→[2]
    - README v9.1
    [TRILHO_FILTRO.scad]
2026-02-09 Fix MONTAGEM_3D: furoYpositions 6→2 valores (12 furos)
2026-02-09 Fix 3D: furos lateral DIR usam mesmos X que trilhos (sem espelhar)
2026-02-09 Parafuso M2x8mm → Allen M2x5mm (3mm MDF + 2mm PLA, sem porca)
    [TRILHO_FILTRO.scad]
2026-02-09 Remove abas divisórias + slots laterais (trilhos 3D substituem)
    - Divisórias 07-10: contorno retângulo simples 244x244mm (sem abas)
    - Laterais 01-02: slots divisórias removidos (3 passes cada)
    - MONTAGEM_3D: removidos slots verdes + abas laranja
    - README v9.2: documentação atualizada
    - 958 linhas removidas — divisórias deslizam nos trilhos
2026-02-09 Divisórias 244x240mm: largura ajustada para caber entre bases dos trilhos
    - Divisórias 07-10: contorno Y 244→240mm, furos recentrados
    - Manta G3: furo Y 22→222 agora 20→220
    - GM: furo Y 17→227 agora 15→225
    - Wega: furo Y 42→202 agora 40→200
    - HEPA: furo Y 52→192 agora 50→190
    - Gaveta (11): contorno 244→240, abas Y 12-52/192-232→10-50/190-230,
    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
2026-02-09 Corrige furos gaveta Y9→10/Y231→230 e comentários centragem Y
    - 11_GAVETA: furos fileira inferior Y=9→10, superior Y=231→230
    (centro correto da borda 20mm: inf 0-20=10, sup 220-240=230)
    - 11_GAVETA: diagrama ASCII restaura X=(62)(102)(142)(182)
    - 07-10: comentários Y centragem corrigidos (240-xxx)/2
2026-02-09 Corrige snap-fit: SCAD vedação 244×240, HTML 16 clips + base flip
    - SNAP_TAMPA.scad: vedacao_divisoria div_size=244 → div_w=244/div_h=240
    - SNAP_FIT_3D.html: texto '8 clips' → '16 clips (8 topo + 8 base)'
    - SNAP_FIT_3D.html: animação clips base (z-base/x-base) agora funciona
    - SNAP_FIT_3D.html: clips base invertidos (scale.y=-1, pernas para cima)
    [SNAP_TAMPA.scad]
2026-02-11 Refactor: arquivos PRINT separados por filtro, remove dovetail, fix Z=0
    - Criados PRINT_*.scad individuais por filtro (Tela Carvao, Manta G3, GM Cabine, HEPA, Wega, Acessorios, Snap Clips, Vedacao)
    - Removido dovetail dos trilhos (bloqueava canal do filtro) - junta reta com cola CA + parafuso M2
    - Corrigido Z alignment: snap clips rotate 180 com translate para Z>=0
    - MONTAGEM_3D.html: dovetail indicator substituido por linha de junta reta
    - Todas as pecas verificadas para caber em 200x200mm (Ender 3)
    - Trilho metade B agora identica a A (sem femea/macho)
    [PRINT_ACESSORIOS.scad, PRINT_GM_CABINE.scad, PRINT_HEPA.scad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]
2026-02-15 v12.0: Aberturas reduzidas + clips parametrizados + limpeza arquivos
    NC Files:
    - 08_DIVISORIA_GM: abertura 212x200mm (era 223x210, filtro nao cai)
    - 09_DIVISORIA_WEGA: abertura 223x160mm, 4 clips so topo/base (sem laterais)
    - 10_DIVISORIA_HEPA: abertura 100x130mm (era 110x140, filtro nao cai)
    - 07_DIVISORIA_MANTA_G3: mantido 200x200mm, 8 clips
    SCAD:
    - SNAP_TAMPA: clip_parafuso_filtro() parametrico por espessura_filtro
    clip_manta(10mm) clip_gm(20mm) clip_wega(10mm) clip_hepa(25mm)
    - PRINT_SNAP_CLIPS: 28 clips em 3 grupos (12x13mm + 8x23mm + 8x28mm)
    Visualizacao:
    - MONTAGEM_3D: aberturas, m3Positions e clips atualizados
    - SNAP_FIT_3D: 32->28 clips retencao
    Limpeza (24 arquivos removidos):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
    [CLIP_GM_CABINE.scad, CLIP_HEPA.scad, CLIP_MANTA_G3.scad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]
2026-02-15 v13.0: cantoneiras M3, clips individuais, SNAP_TAMPA atualizado
    [PRINT_CLIP_GM.scad, PRINT_CLIP_HEPA.scad, PRINT_CLIP_MANTA.scad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]
2026-02-15 caixaplastica v4.0: guias piso 50mm + barras anti-tombo no aro
    [GUIA_POSICAO.scad]
